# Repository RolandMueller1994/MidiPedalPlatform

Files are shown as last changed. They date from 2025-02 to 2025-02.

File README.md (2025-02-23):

# MidiPedalPlatform

## Introduction

This project contains a template PCB for guitar effect pedals with MIDI remote functionality. MIDI is implemented using a STM32 F030C8T6 microcontroller.
The PCB is setup to contain four 16mm potentiometers, a SPST on-off-on switch and PCB mounted jack sockets for audio connection. Further connections are the MIDI input and output, an internal switch and an external switch which are all accesible through JST connectors. A programming and debugging connector for the STLINK-V3MINIE is implemented on the PCB.

Following images show a complete pedal build based on this template.

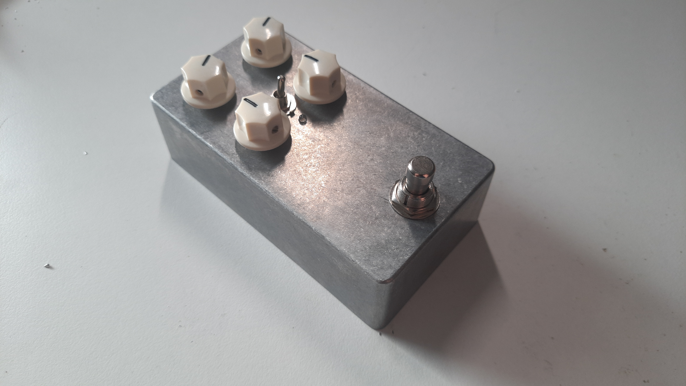
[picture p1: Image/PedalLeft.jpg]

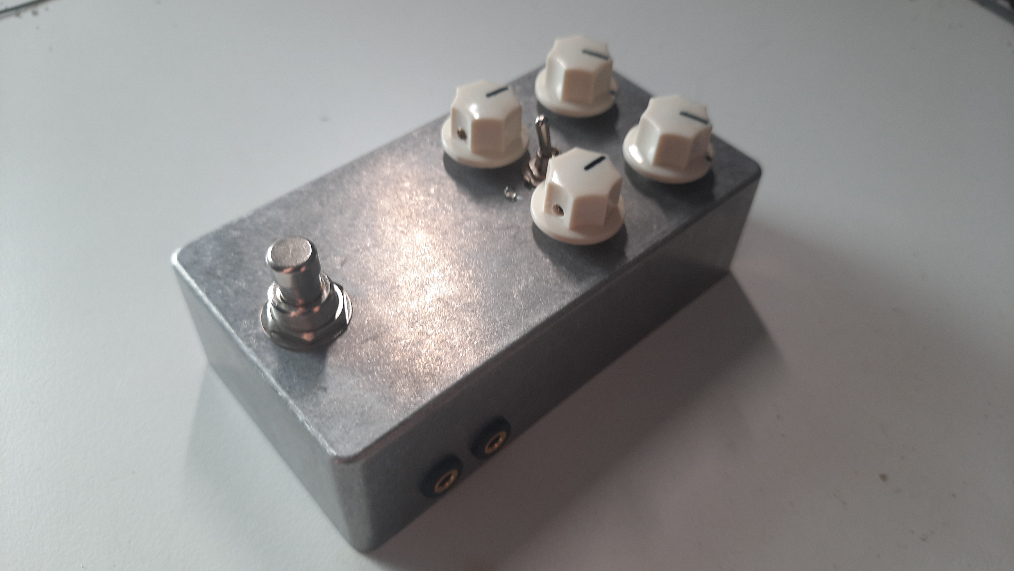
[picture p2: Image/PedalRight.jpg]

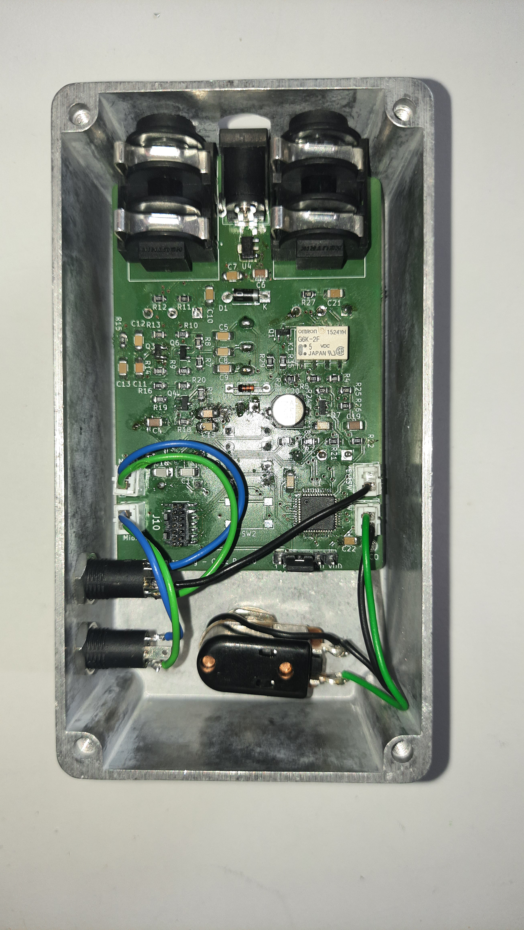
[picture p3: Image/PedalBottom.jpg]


## PCB

The PCB was developed using KiCad and a two layer setup. The KiCad project can be found in [PCB/MidiPedalPlatform](PCB/MidiPedalPlatform) whilst PCB and schematic exports are located in [PCB/Export](PCB/Export).

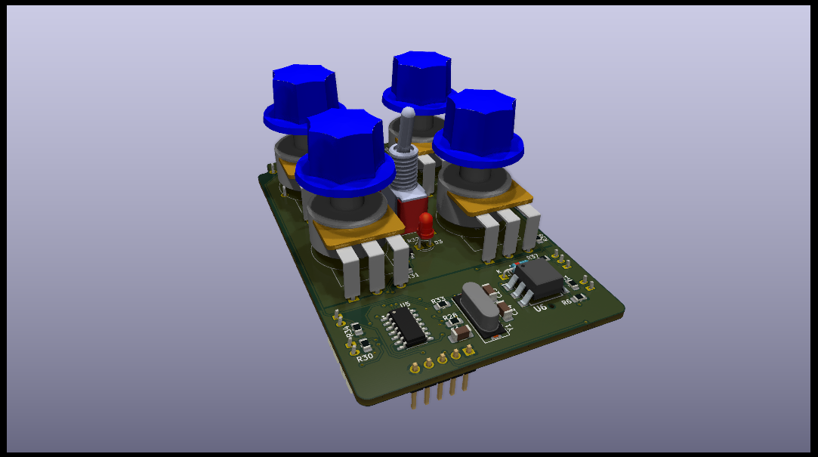
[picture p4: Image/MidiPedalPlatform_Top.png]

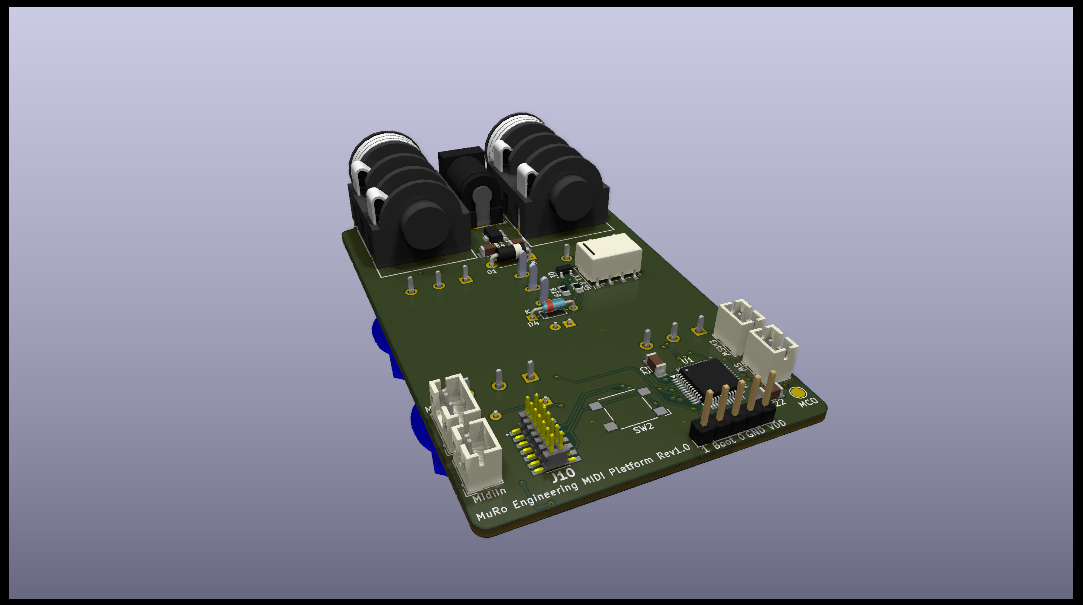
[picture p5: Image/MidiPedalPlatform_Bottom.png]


## Firmware

The MCU firmware is located in the [Firmware](Firmware) directory. It is implemented as STM32CubeIDE project.

The firmware handles switches and MIDI messages. By default, two switches are available: SW and ExtSW. SW is meant to be used as the default internal footswitch and must be a momentary switch. ExtSW can be used to connect an external remote switch and is by default configured to be a latching switch. This can be changed by changing:
```C
bool swLatches[NO_SWITCHES] = { false, true, true }
```
to
```C
bool swLatches[NO_SWITCHES] = { false, false, true }
```
The pedal can be switched on and off via MIDI CC commands. The channel and controller number are stored in the flash memory. Thus, a MIDI learn state and a reset state have been implemented.
To reset both parameters to their default value (channel=0, controller=20), hold the footswitch pressed (SW) while powering on or reseting the MCU till the LED starts blinking. Release the switch afterwards and the LED stops blinking. Default values will then have been written to flash.

MIDI learn is used to set any other channel and controller. This mode can be accessed by holding the footswitch pressed whilst the input jack is not connected. The LED starts blinking once MIDI learn state has been reached. In this mode, the firmware waits for a MIDI CC message and once the first one has been received, it will store the channel and controller of this message in the flash memory. MIDI learn can be aborted by pressing the footswitch again. In either case, MIDI CC received or MIDI learn aborted, the LED stops blinking.
The pedal can be switched on by sending a value greater than 63 to the configured MIDI contoller. Anything lower or equal than 63 will switch off the pedal.

The footswitch can be used in two different ways. 

- Normal activation: Toggles between on and off state
- Keeping the switch pressed whilst the pedal was off: The pedal will turn on as long you keep the switch pressed. Once release, the pedal will turn off.

## Enclosure

The PCB was design to fit into a 1590N1 enclosure. A FreeCAD project including enclosure, PCB, jacks and the switch can be found at [Enclosure/Enclosure.FCStd](Enclosure/Enclosure.FCStd). Renderings of the enclosure can be found below.
Drill templates can be found in [Enclosure/DrillTemplates](Enclosure/DrillTemplates).

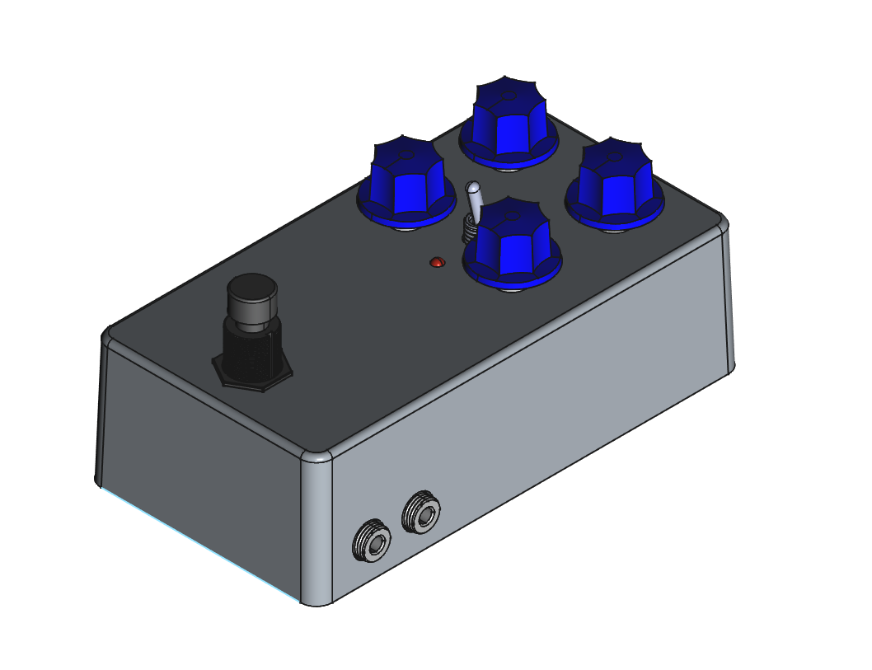
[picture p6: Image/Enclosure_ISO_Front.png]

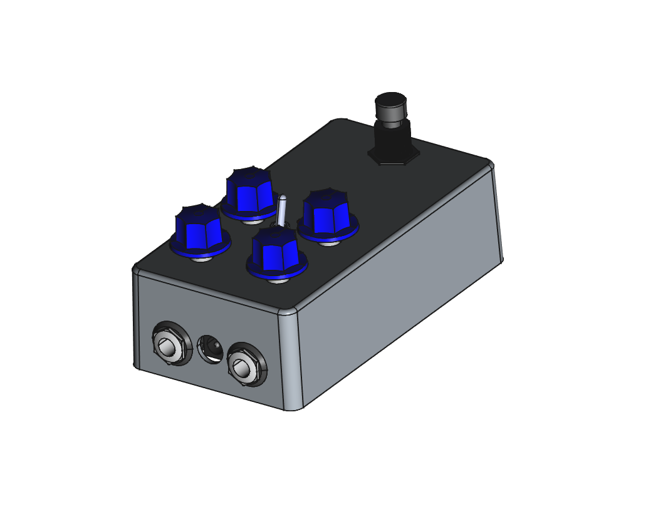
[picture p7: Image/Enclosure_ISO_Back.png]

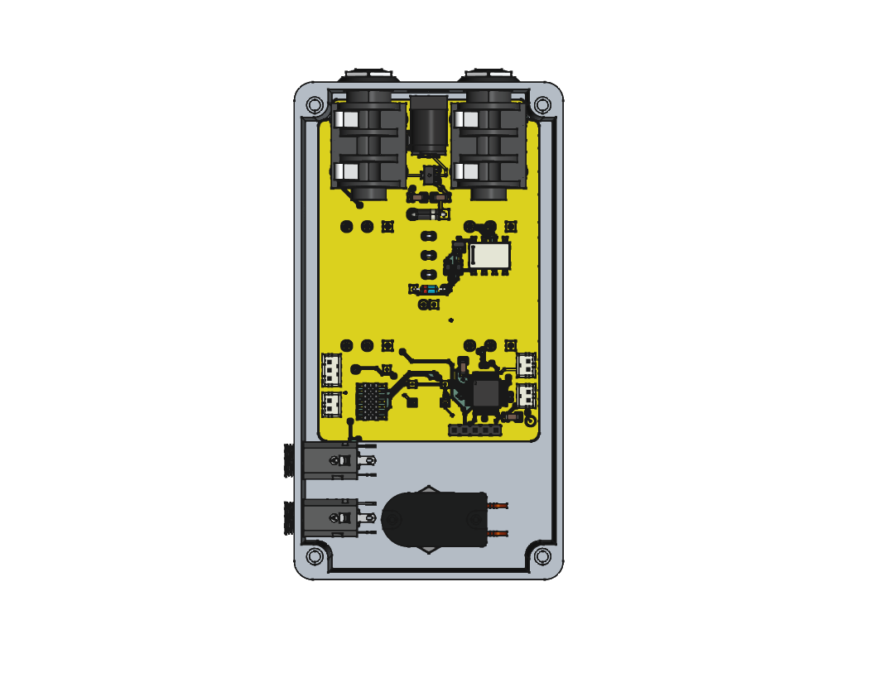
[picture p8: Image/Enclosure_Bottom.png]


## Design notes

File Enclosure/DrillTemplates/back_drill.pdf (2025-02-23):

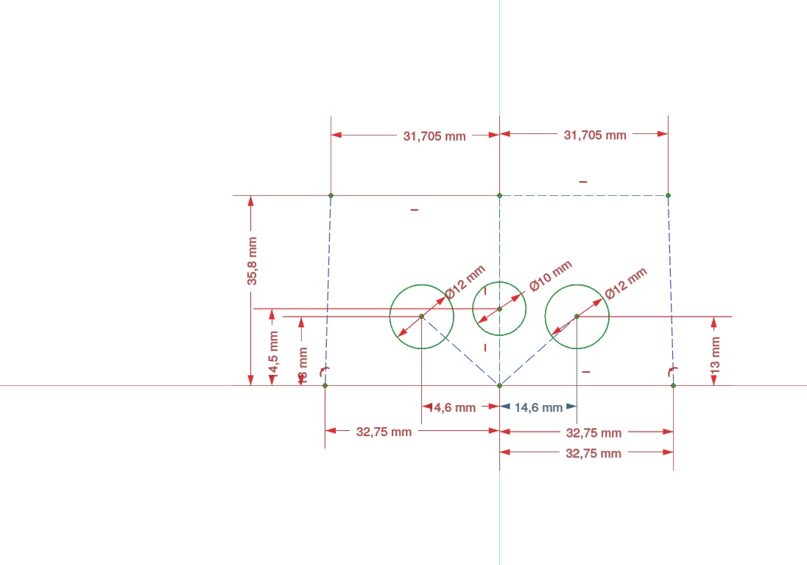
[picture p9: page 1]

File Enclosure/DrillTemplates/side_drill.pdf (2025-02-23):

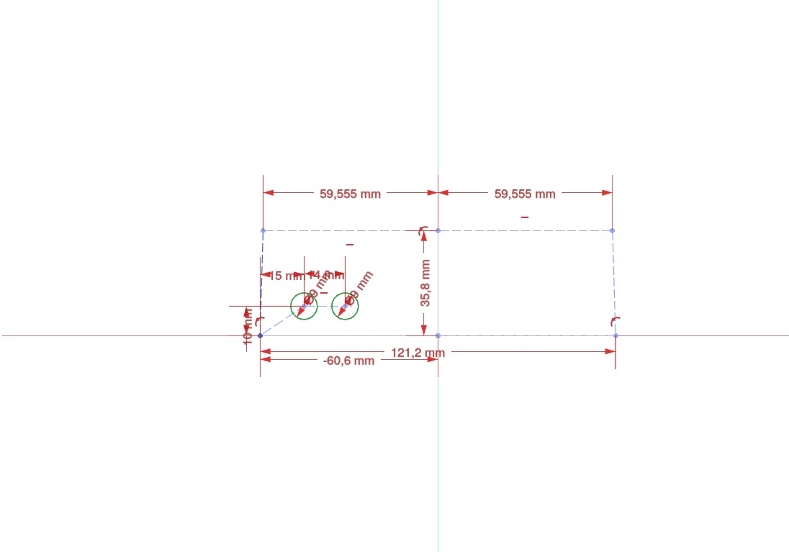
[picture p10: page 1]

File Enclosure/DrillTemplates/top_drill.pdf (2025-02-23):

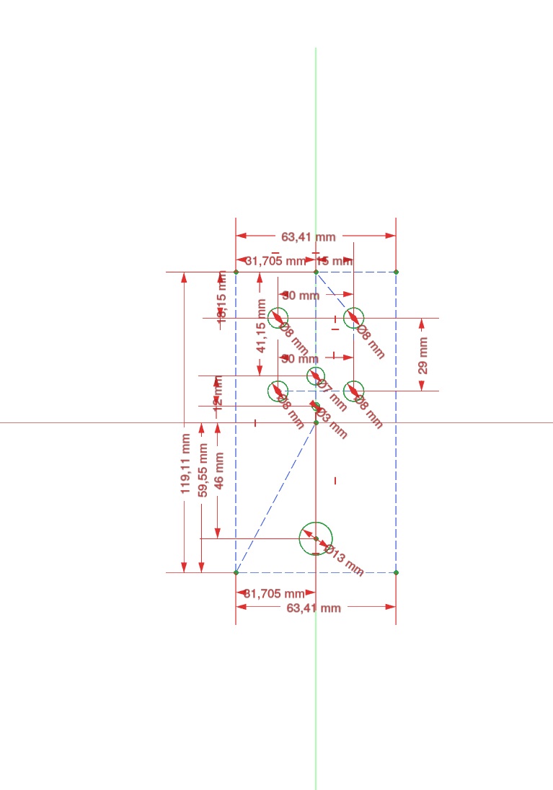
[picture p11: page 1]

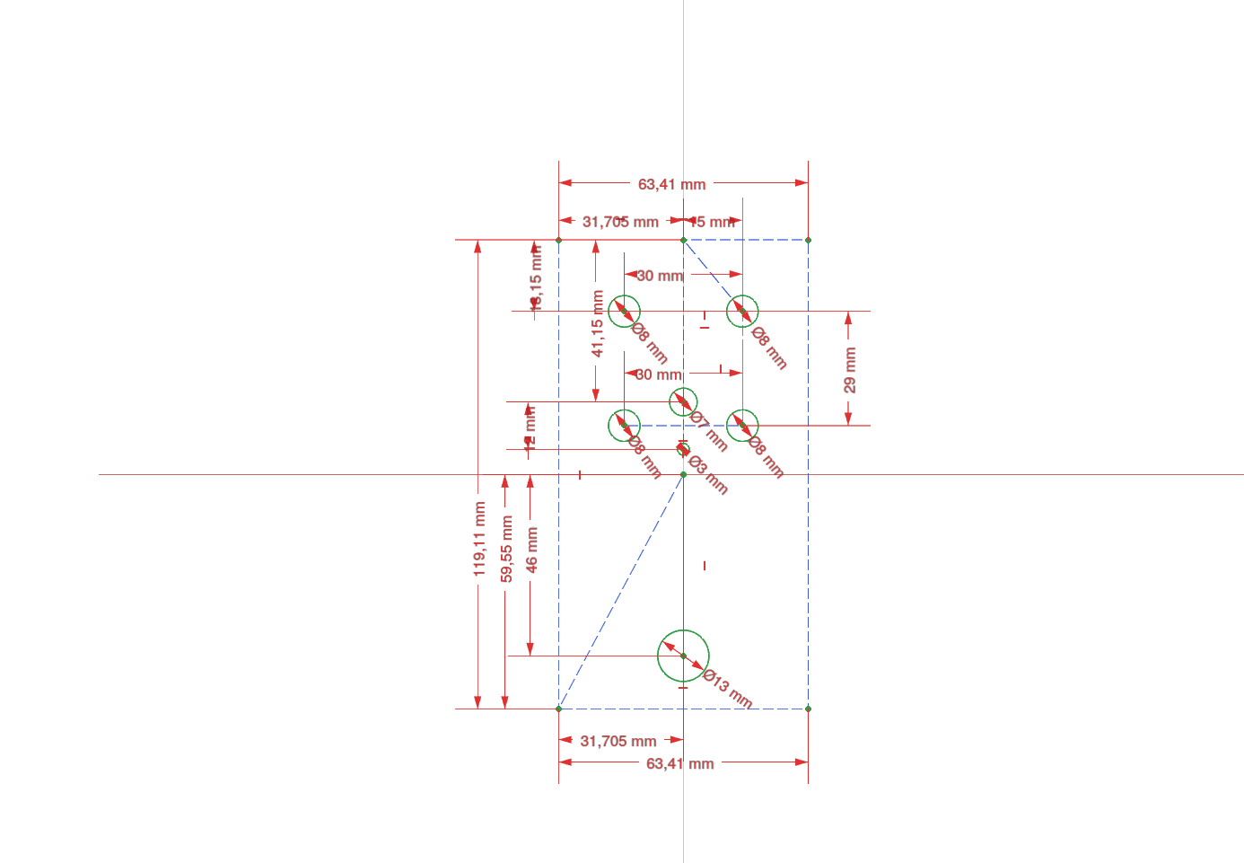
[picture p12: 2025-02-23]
Enclosure/DrillTemplates/top_drill.png

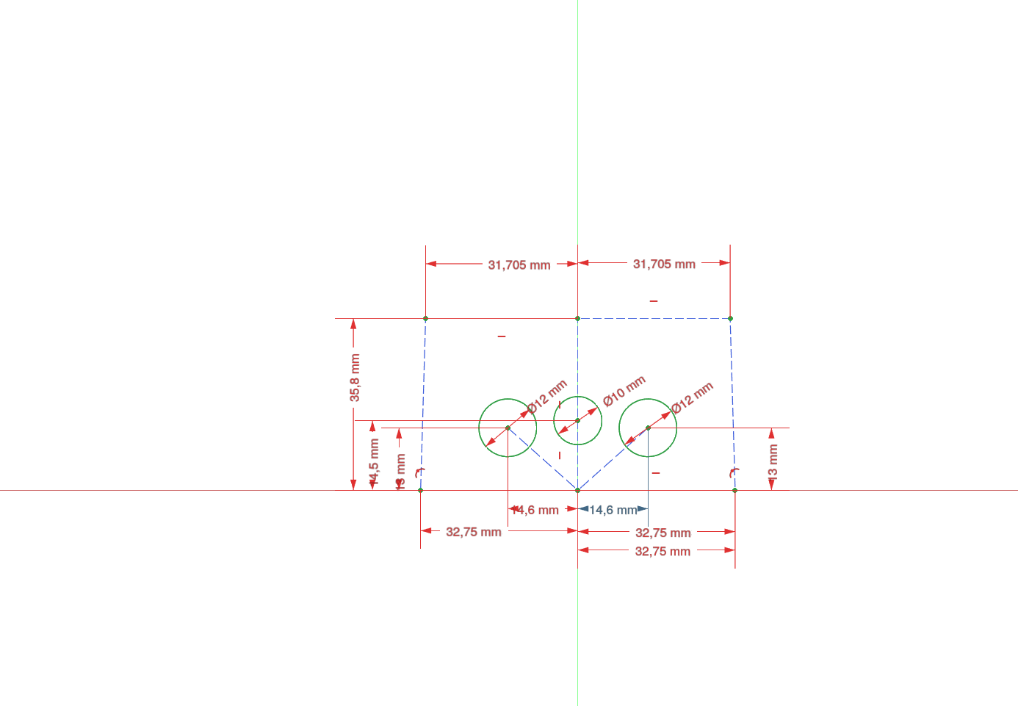
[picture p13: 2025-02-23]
Enclosure/DrillTemplates/back_drill.png

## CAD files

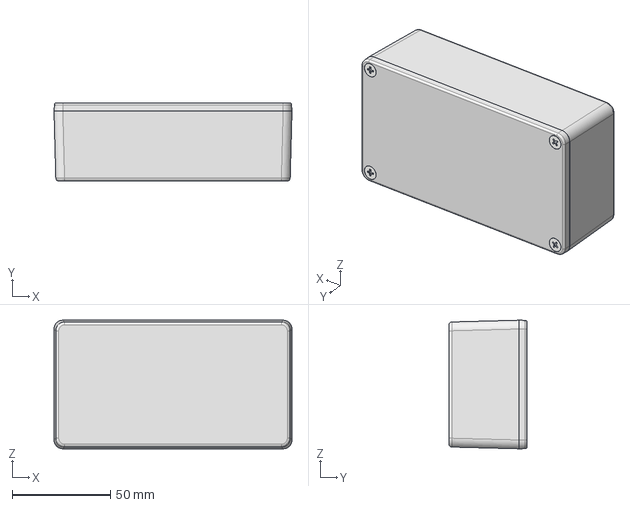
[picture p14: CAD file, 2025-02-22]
Enclosure/1590N1.stp
121.2 x 39.8 x 65.5 mm

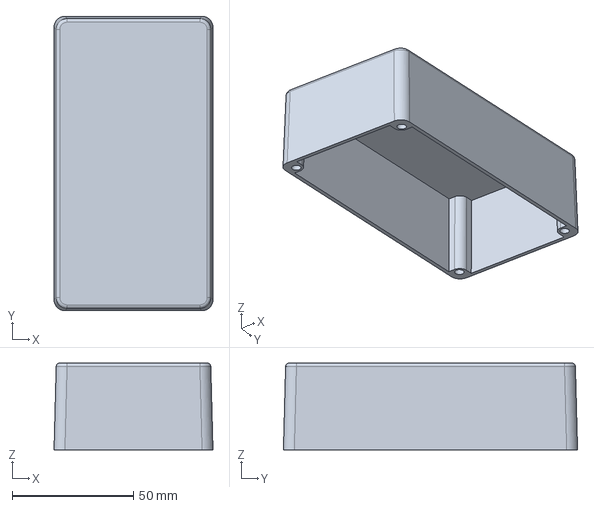
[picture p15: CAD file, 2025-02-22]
Enclosure/Enclosure.FCStd
65.5 x 121.2 x 35.8 mm

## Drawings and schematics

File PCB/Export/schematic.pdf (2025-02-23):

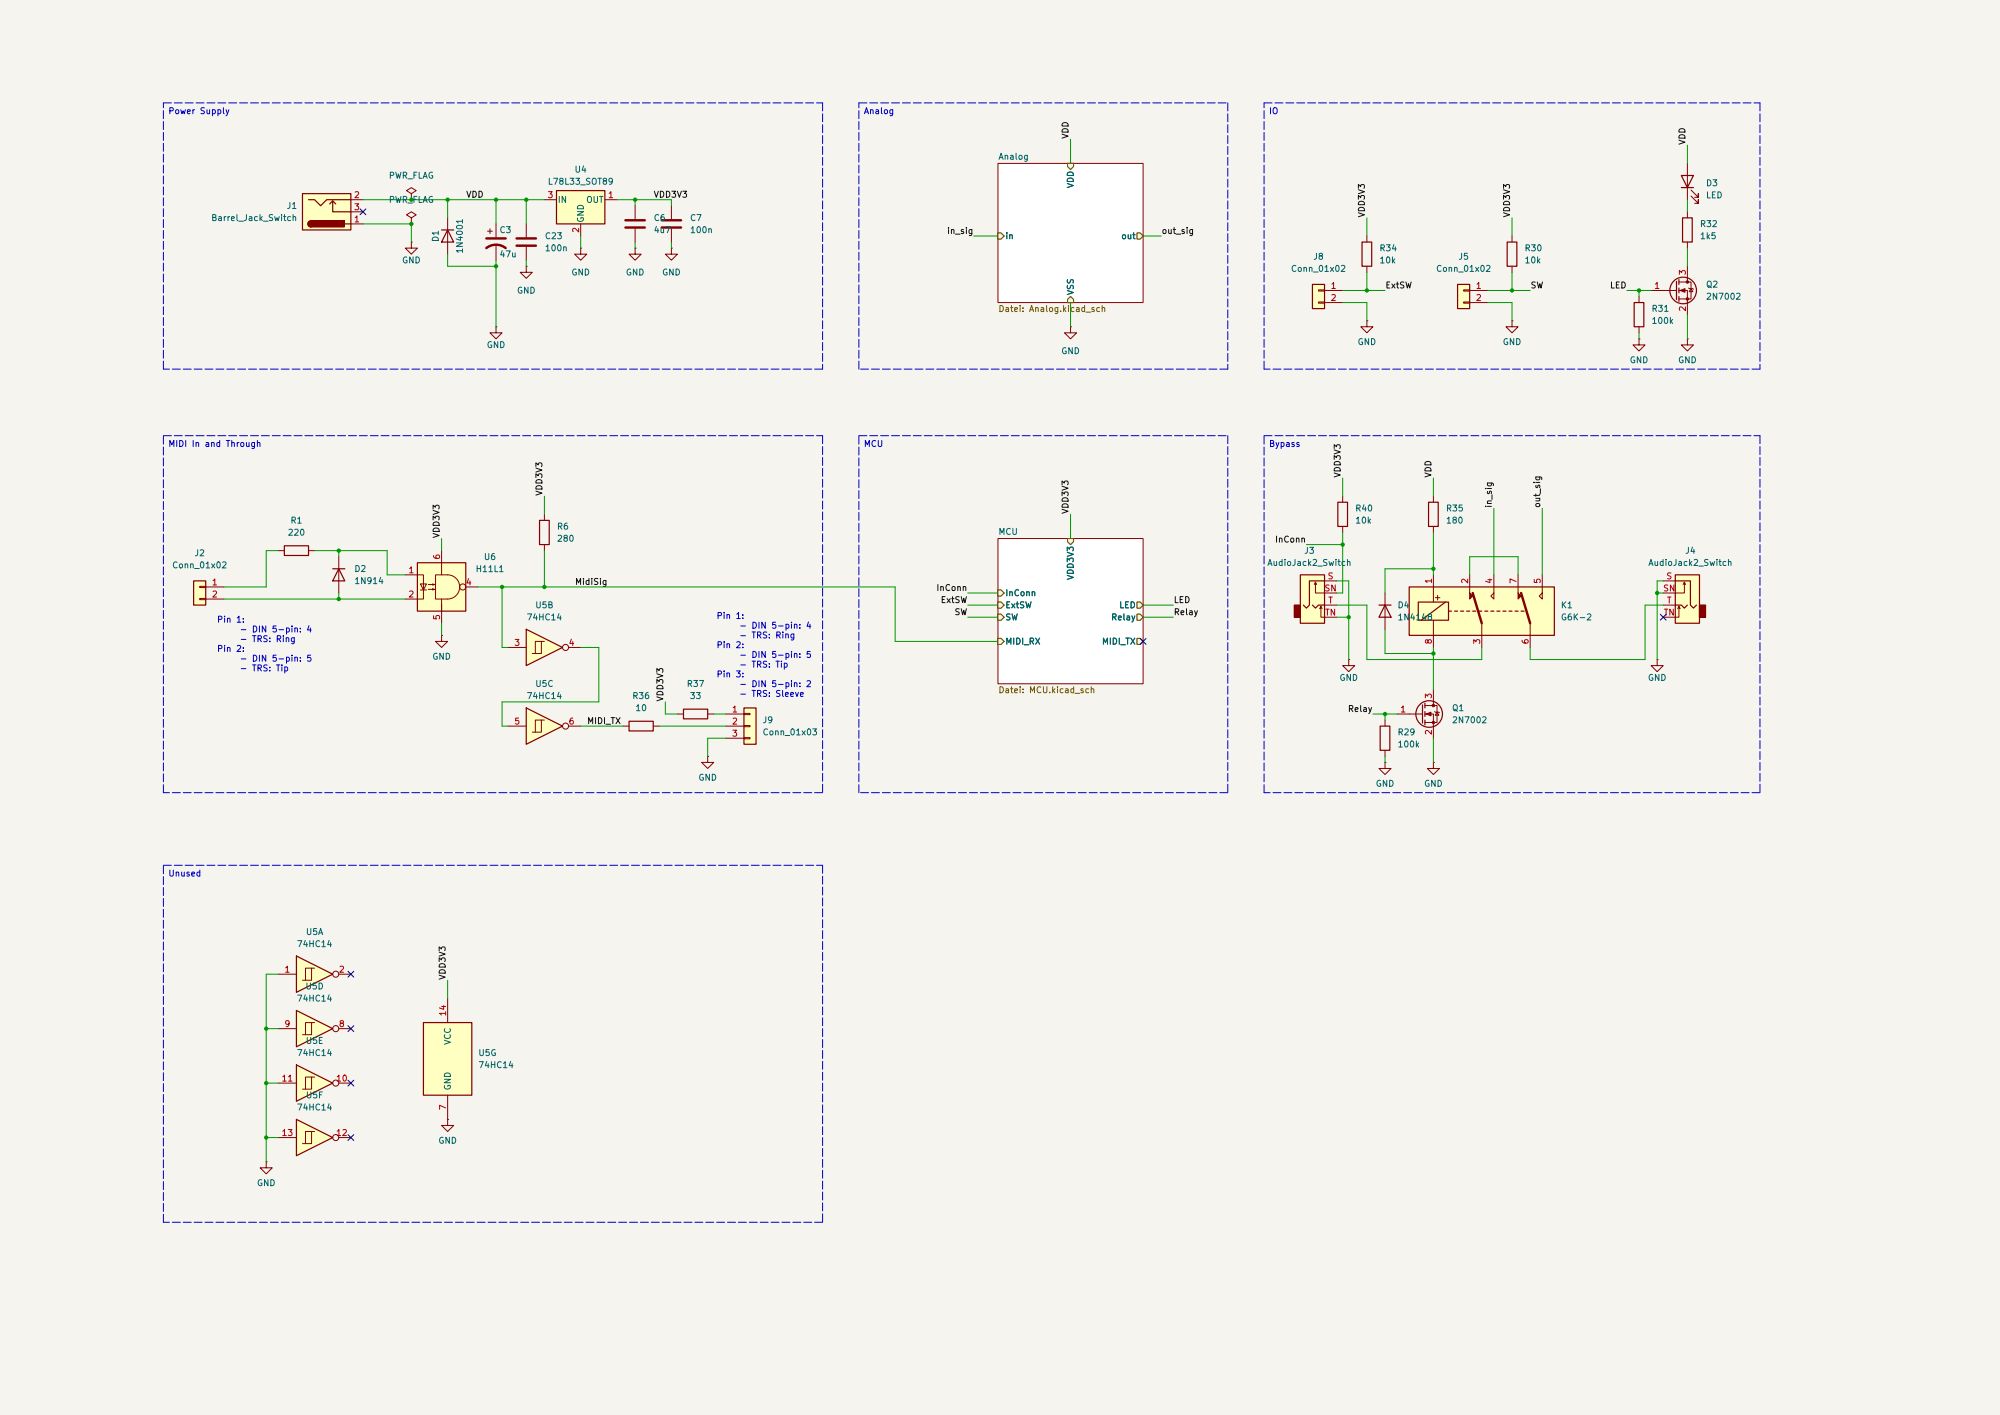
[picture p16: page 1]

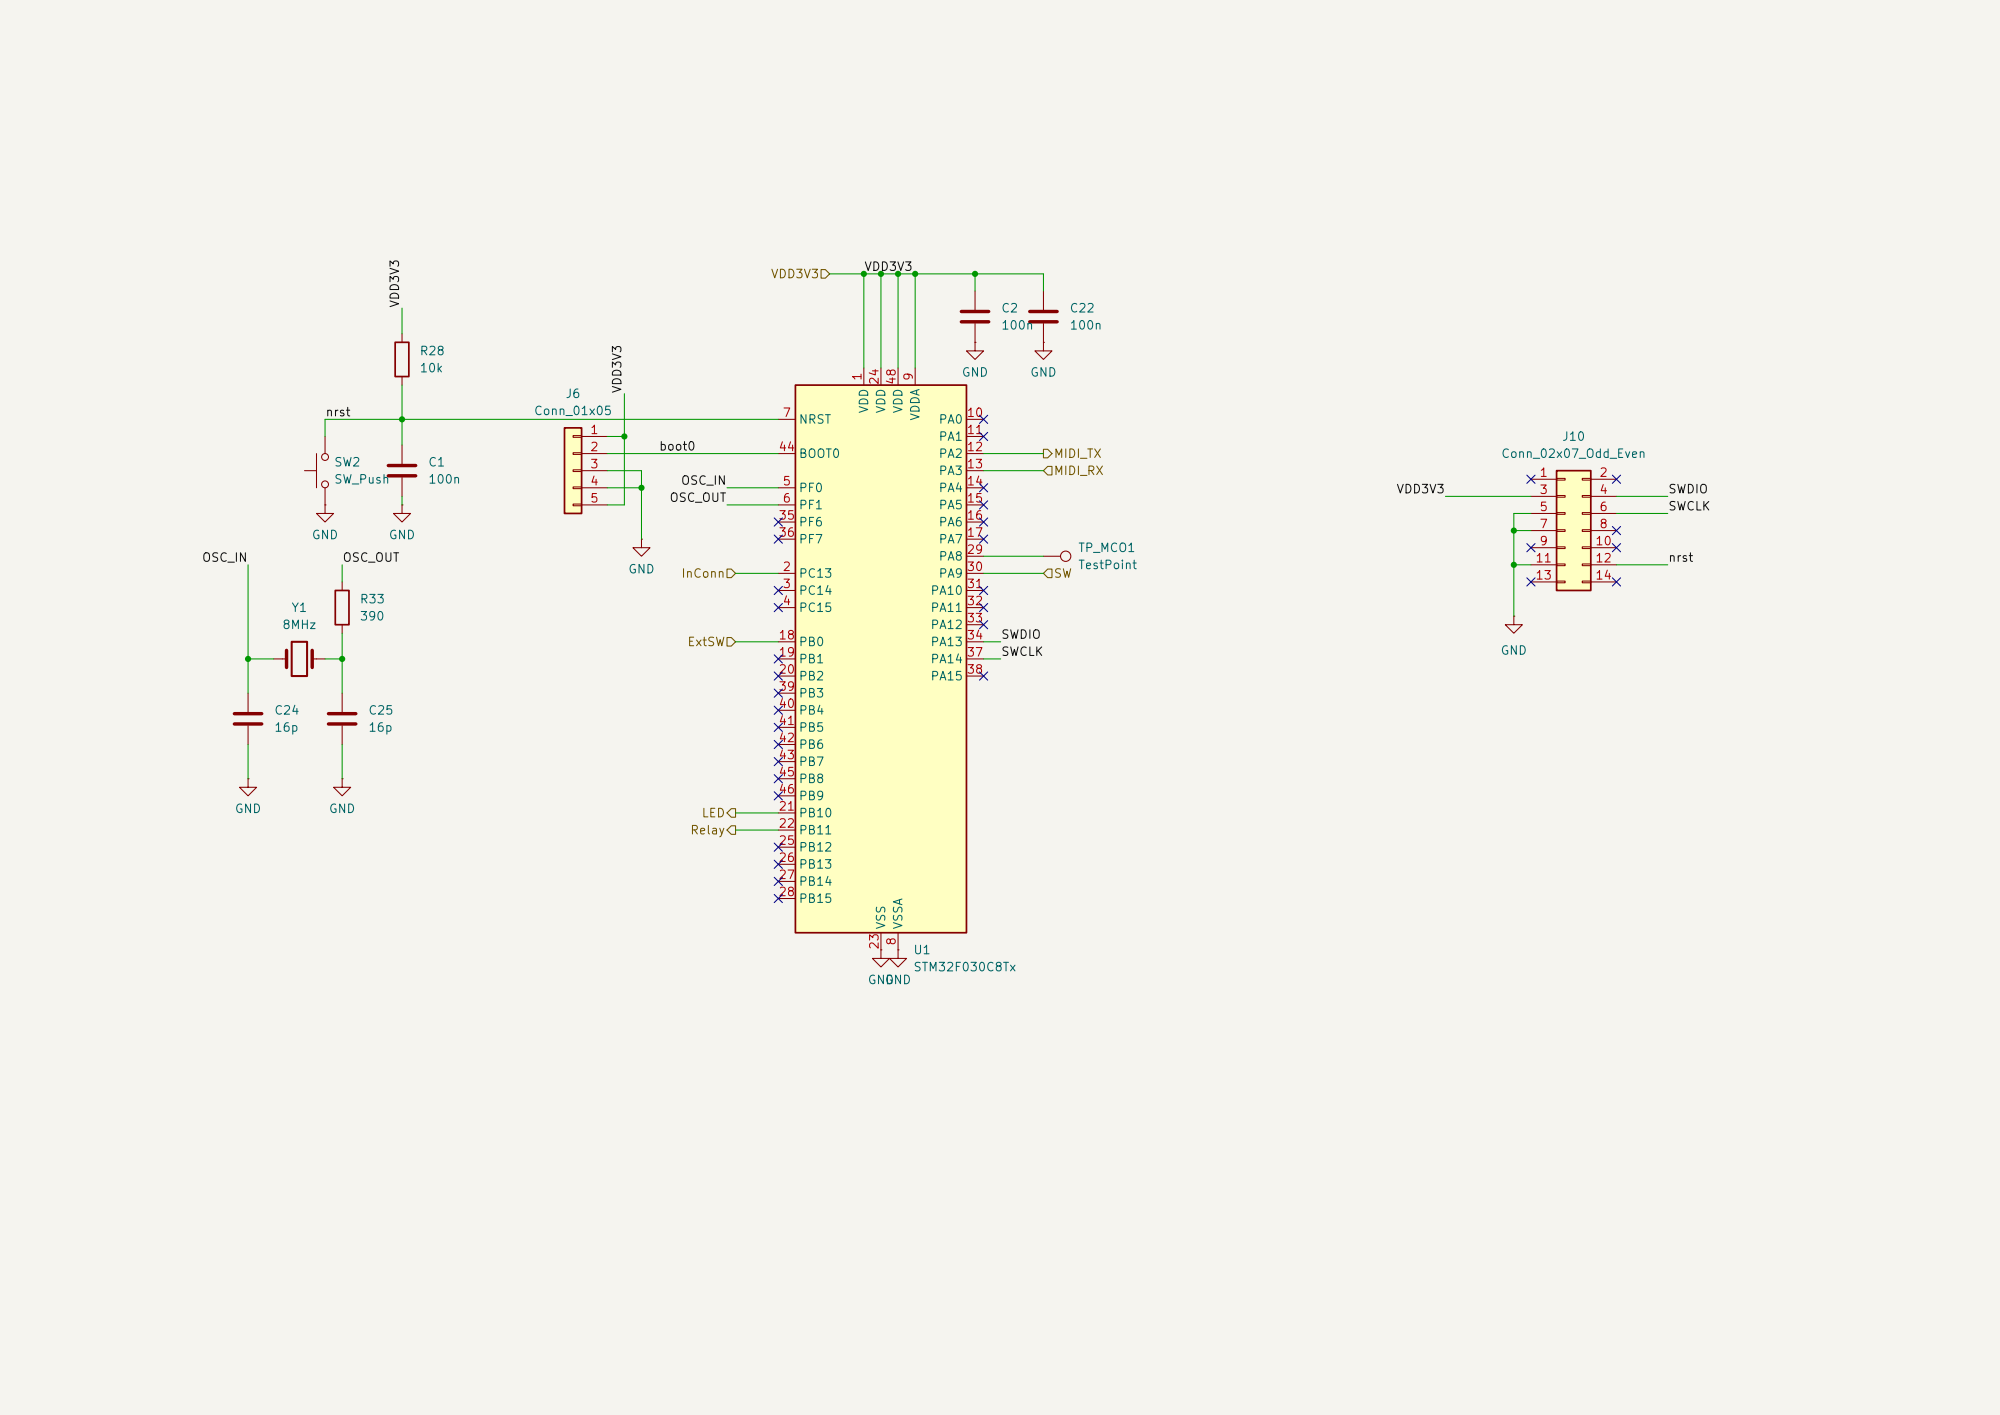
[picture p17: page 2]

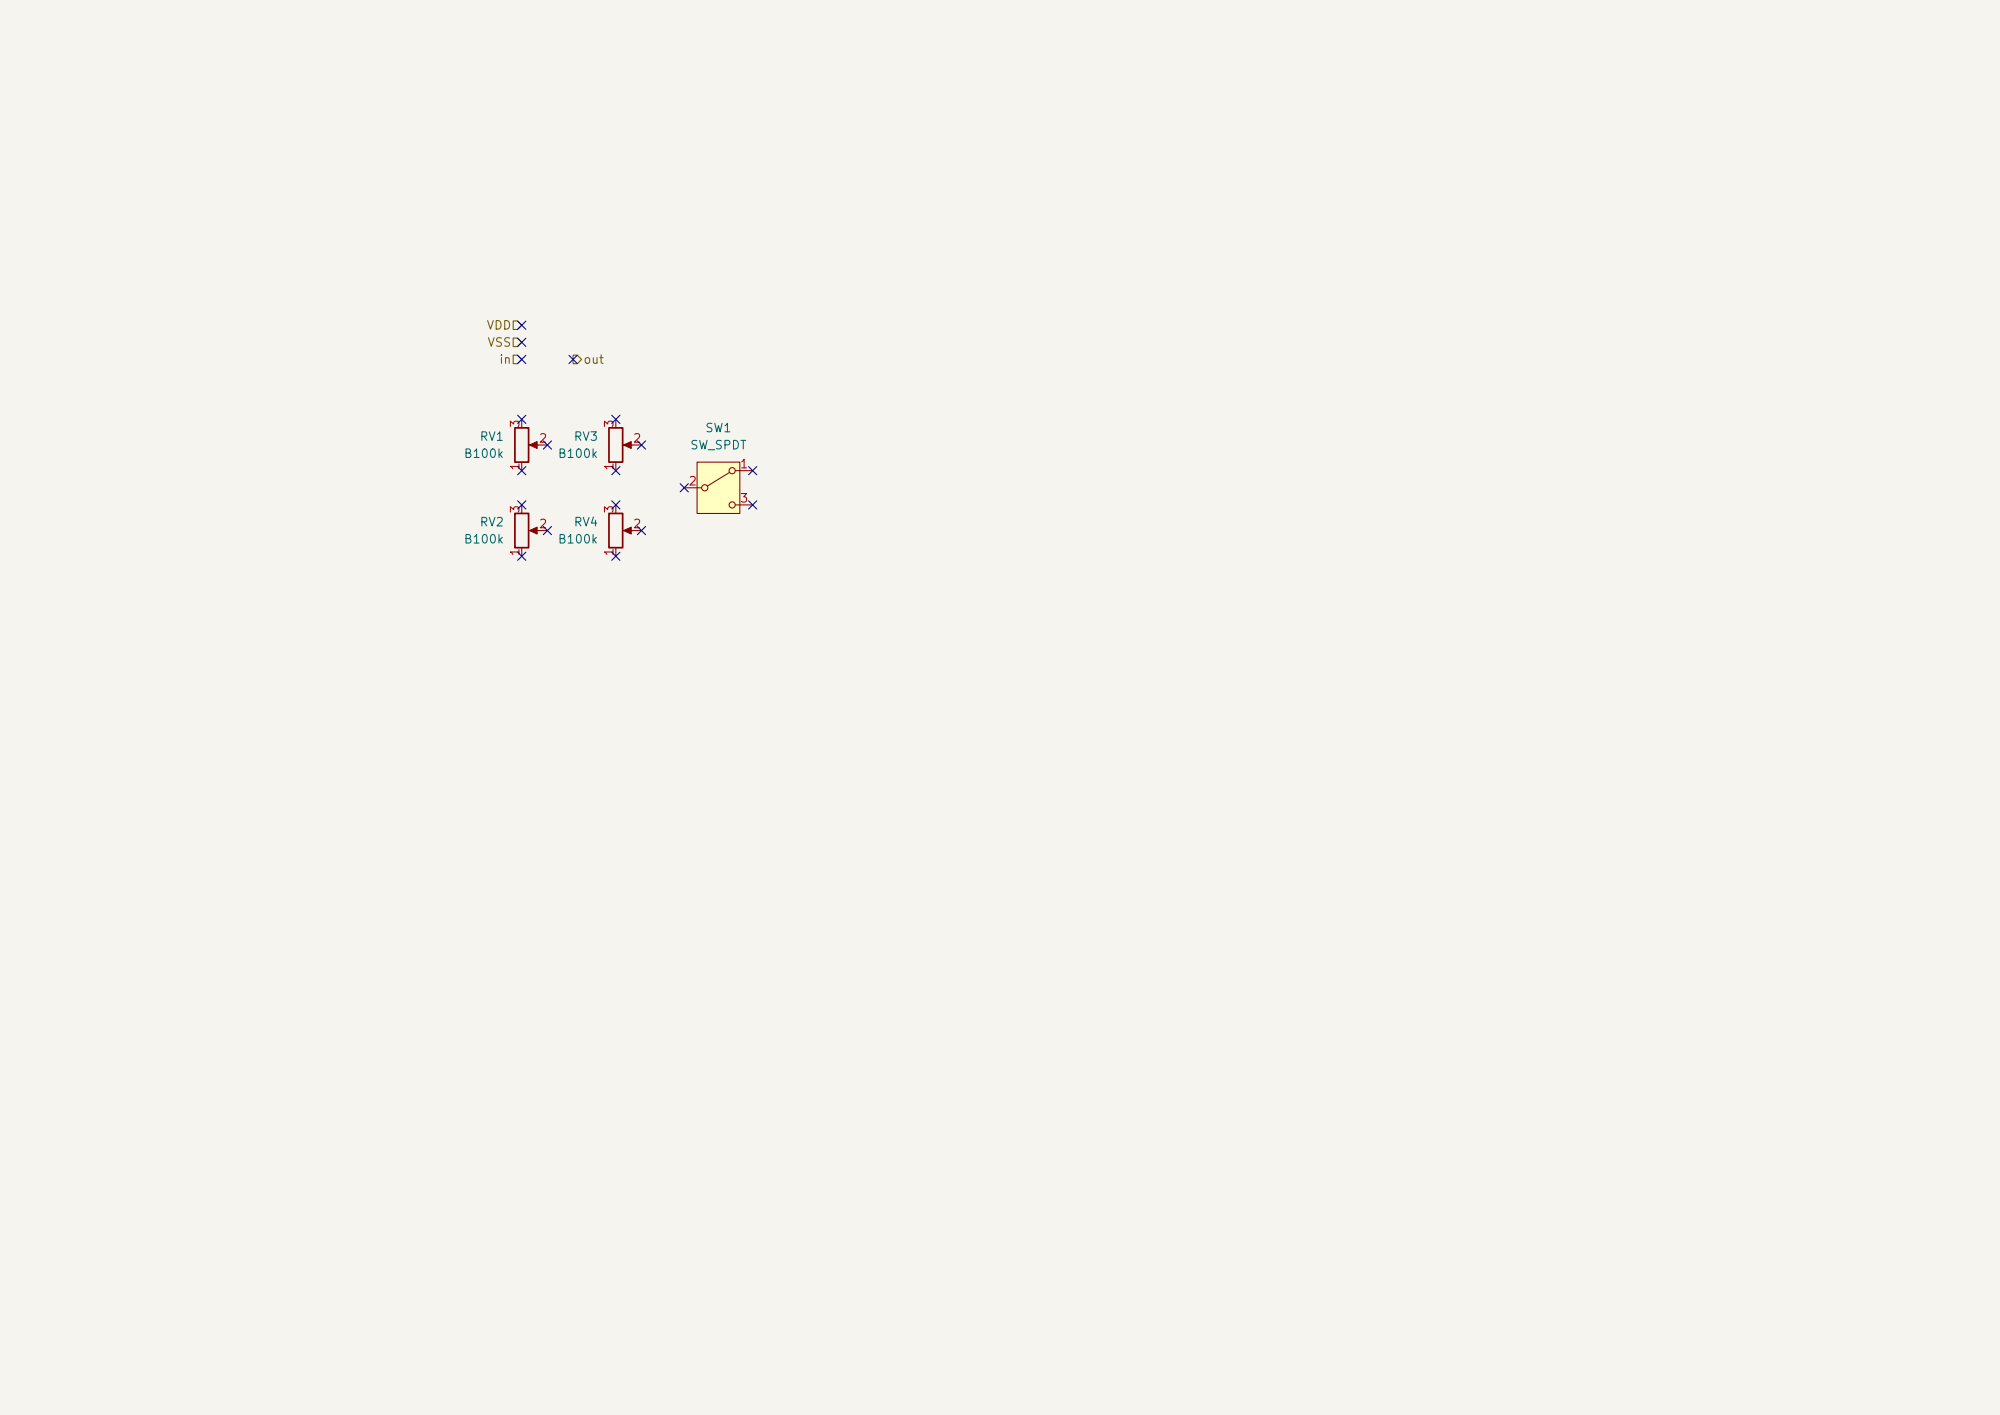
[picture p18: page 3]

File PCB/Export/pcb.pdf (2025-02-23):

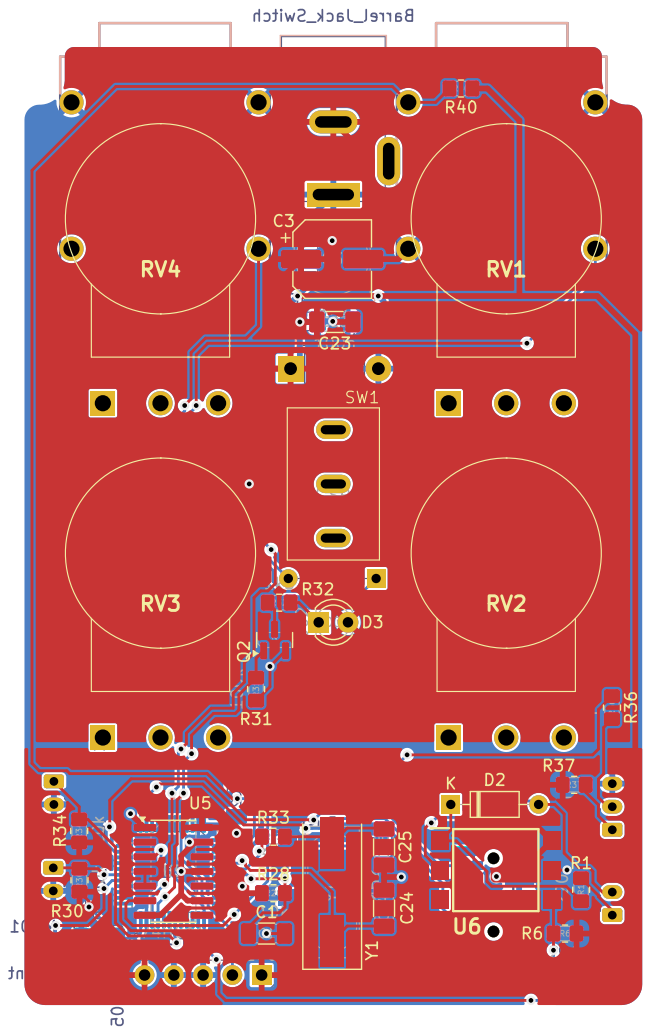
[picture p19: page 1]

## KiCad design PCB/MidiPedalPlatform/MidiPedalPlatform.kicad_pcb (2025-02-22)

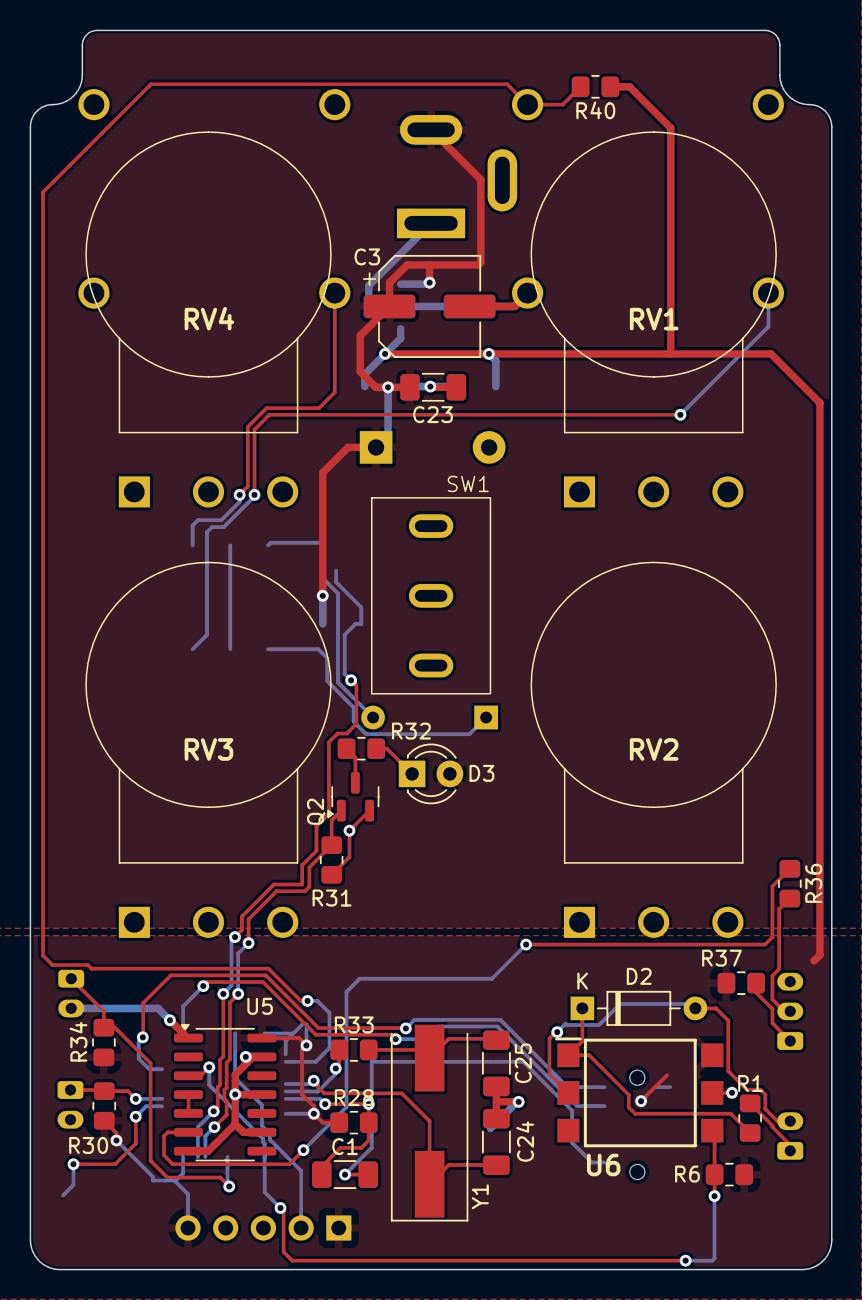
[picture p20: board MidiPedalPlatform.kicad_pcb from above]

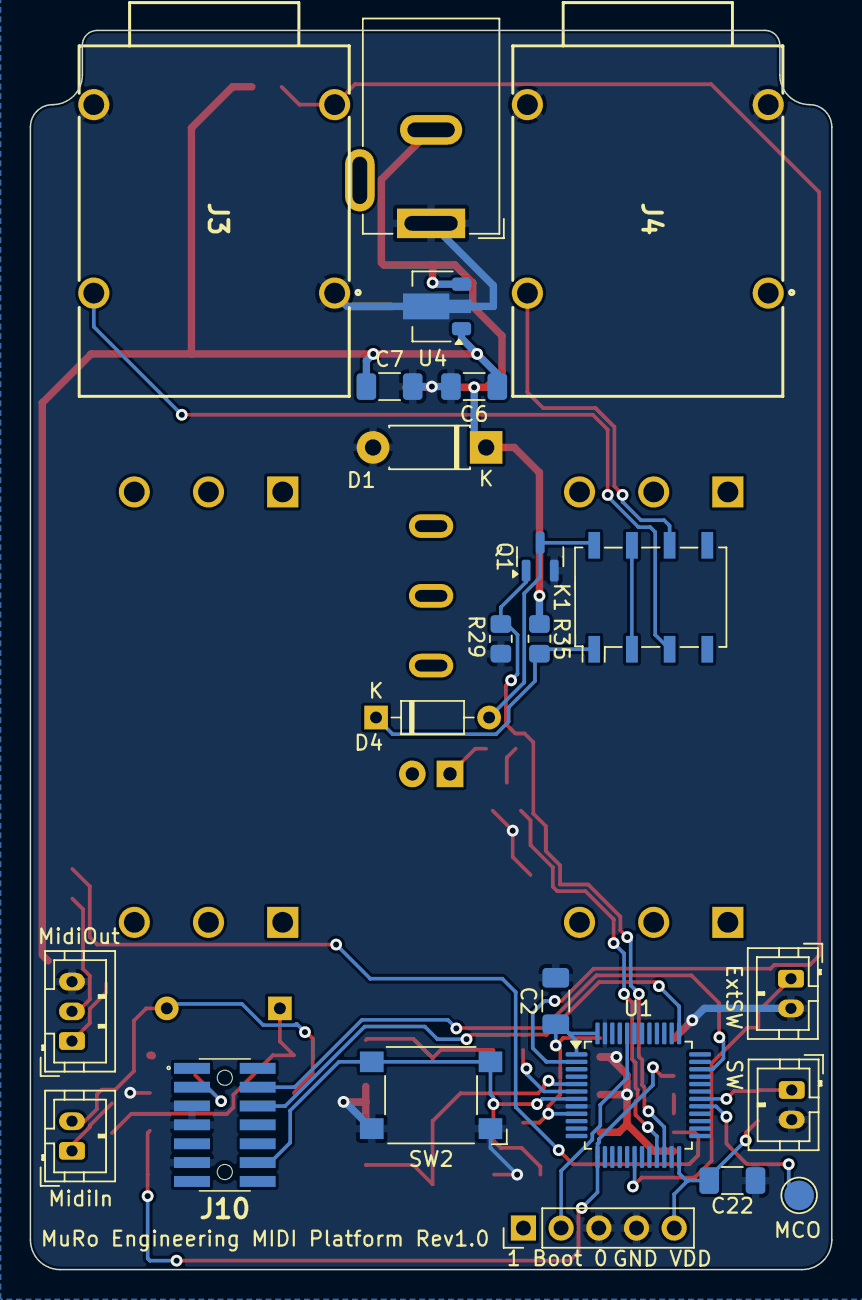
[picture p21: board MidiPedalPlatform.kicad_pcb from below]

Board: 2 copper layers, 54.0 x 83.5 mm, 50 parts (23 on the bottom side), 31 nets.

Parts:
C1, C2, C7, C22, C23: 100n; C_1206_3216Metric_Pad1.33x1.80mm_HandSolder
C3: 47u; CP_Elec_6.3x5.8
C6: 4u7; C_1206_3216Metric_Pad1.33x1.80mm_HandSolder
C24, C25: 16p; C_1206_3216Metric_Pad1.33x1.80mm_HandSolder
D1: 1N4001; D_DO-41_SOD81_P7.62mm_Horizontal
D2: 1N914; D_DO-35_SOD27_P7.62mm_Horizontal
D3: LED; LED_D3.0mm
D4: 1N4148; D_DO-35_SOD27_P7.62mm_Horizontal
J1: Barrel_Jack_Switch; BarrelJack_GCT_DCJ200-10-A_Horizontal
J2, J5, J8: Conn_01x02; JST_PH_B2B-PH-K_1x02_P2.00mm_Vertical
J3, J4: AudioJack2_Switch; NMJ4HCD2
J6: Conn_01x05; PinHeader_1x05_P2.54mm_Vertical
J9: Conn_01x03; JST_PH_B3B-PH-K_1x03_P2.00mm_Vertical
J10: Conn_02x07_Odd_Even; FTSH-107-XX-YYY-DV-K-A
K1: G6K-2; Relay_DPDT_Omron_G6K-2F
Q1, Q2: 2N7002; SOT-23
R1: 220; R_0805_2012Metric_Pad1.20x1.40mm_HandSolder
R6: 280; R_0805_2012Metric_Pad1.20x1.40mm_HandSolder
R28, R30, R34, R40: 10k; R_0805_2012Metric_Pad1.20x1.40mm_HandSolder
R29, R31: 100k; R_0805_2012Metric_Pad1.20x1.40mm_HandSolder
R32: 1k5; R_0805_2012Metric_Pad1.20x1.40mm_HandSolder
R33: 390; R_0805_2012Metric_Pad1.20x1.40mm_HandSolder
R35: 180; R_0805_2012Metric_Pad1.20x1.40mm_HandSolder
R36: 10; R_0805_2012Metric_Pad1.20x1.40mm_HandSolder
R37: 33; R_0805_2012Metric_Pad1.20x1.40mm_HandSolder
RV1, RV2, RV3, RV4: B100k; RV16AF_Mono
SW1: SW_SPDT; Switch_SPDT
SW2: SW_Push; SW_SPST_Omron_B3FS-100xP
TP_MCO1: TestPoint; TestPoint_Pad_D2.0mm
U1: STM32F030C8Tx; LQFP-48_7x7mm_P0.5mm
U4: L78L33_SOT89; SOT-89-3
U5: 74HC14; SO-14_3.9x8.65mm_P1.27mm
U6: H11L1; H11L1SM
Y1: 8MHz; Crystal_SMD_HC49-SD

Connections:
/ExtSW: J8.1, R34.2, U1.18 (PB0)
/InConn: J3.SN, R40.2, U1.2 (PC13)
/LED: Q2.1 (G), R31.1, U1.21 (PB10)
/MCU/OSC_IN: C24.1, U1.5 (PF0), Y1.1
/MCU/OSC_OUT: R33.1, U1.6 (PF1)
/MCU/SWCLK: J10.6, U1.37 (PA14)
/MCU/SWDIO: J10.4, U1.34 (PA13)
/MCU/boot0: J6.2, U1.44 (BOOT0)
/MCU/nrst: C1.1, J10.12, R28.2, SW2.2, U1.7 (NRST)
/MIDI_TX: R36.1, U5.6
/MidiSig: R6.1, U1.13 (PA3), U5.3, U6.4
/Relay: Q1.1 (G), R29.1, U1.22 (PB11)
/SW: J5.1, R30.2, U1.30 (PA9)
/VDD: C3.1, C23.1, D1.1 (K), D3.2 (A), J1.2, R35.1, U4.3 (IN)
/VDD3V3: C2.1, C6.1, C7.1, C22.1, J6.1, J6.5, J10.3, R6.2, R28.1, R30.1, R34.1, R37.1, R40.1, U1.1 (VDD), U1.9 (VDDA), U1.24 (VDD), U1.48 (VDD), U4.1 (OUT), U5.14 (VCC), U6.6
GND: C1.2, C2.2, C3.2, C6.2, C7.2, C22.2, C23.2, C24.2, C25.2, D1.2 (A), J1.1, J3.S, J3.TN, J4.S, J4.SN, J5.2, J6.3, J6.4, J8.2, J9.3, J10.5, J10.7, J10.11, Q1.2 (S), Q2.2 (S), R29.2, R31.2, SW2.1, U1.8 (VSSA), U1.23 (VSS), U1.47 (VSS), U4.2 (GND), U5.1, U5.7 (GND), U5.9, U5.11, U5.13, U6.5
unnamed: C25.1, R33.2, Y1.2
unnamed: D2.2 (A), J2.2, U6.2
unnamed: D2.1 (K), R1.2, U6.1
unnamed: D3.1 (K), R32.1
unnamed: D4.2 (A), K1.8, Q1.3 (D)
unnamed: D4.1 (K), K1.1, R35.2
unnamed: J2.1, R1.1
unnamed: J3.T, K1.3
unnamed: J4.T, K1.6
unnamed: J9.1, R37.2
unnamed: J9.2, R36.2
unnamed: K1.2, K1.7
unnamed: Q2.3 (D), R32.2
unnamed: TP_MCO1.1, U1.29 (PA8)
unnamed: U5.4, U5.5

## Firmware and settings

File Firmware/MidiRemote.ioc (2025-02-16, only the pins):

Mcu.UserName=STM32F030C8Tx
PA13.Signal=SYS_SWDIO
PA14.Signal=SYS_SWCLK
PA2.Signal=USART2_TX
PA3.Signal=USART2_RX
PA8.Signal=RCC_MCO
PA9.GPIO_Label=SW
PA9.Signal=GPIO_Input
PB0.GPIO_Label=ExtSW
PB0.Signal=GPIO_Input
PB10.GPIO_Label=LED
PB10.Signal=GPIO_Output
PB11.GPIO_Label=Relay
PB11.Signal=GPIO_Output
PC13.GPIO_Label=InConn
PC13.Signal=GPIO_Input
PF0-OSC_IN.Signal=RCC_OSC_IN
PF1-OSC_OUT.Signal=RCC_OSC_OUT

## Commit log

2025-02-16 Imported firmware with basic hardware configuration. This is a clean STM32 project for the target microcontroller including the IO configuration.
2025-02-16 First version of switch debouncing.
    In this version, momentary switches are properly debounced and their state is traced for falling edge (active low) operation.
    Dual edge debouncing and latching switch operation yet to be implemented.
2025-02-16 Added push and release edge detection and debouncing.
    With this change, lateched switches can be used to trigger the effectOn state by tracking the edges.
2025-02-16 Added long press functionality for momentary switches.
    This feature detects momentary switches been pressed for longer than a certain time (LONG_DELAY). This can be used to temporarily activate the effect as long as the switched is pressed. After release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
2025-02-16 Switched UART to UARTEx functions to use ReceiveToIdle functions.
    MIDI packages are either two or three bytes long. Thus, e.g. PC messages would not fill the whole RX buffer and therefore mess up the package sequence.
    ReceiveToIdle executes the callback once the length is reached or no further data is transfered (idle). Therefore, the interupts are called after each MIDI package no matter the length.
2025-02-16 Added MIDI learn functionality and reset.
    If the main switch is pressed at power on, default MIDI channel 1 and controller 20 are stored.
    If the main switch is pressed during operation and the input jack is not connected, MIDI learn is started. In this case, the device waits till it receives the first CC message. The channel and controller are stored afterwards.
    [main.c]
2025-02-18 Addition of periodic UART overrun check.
    UART gets into overrun condition once it receives data and the previous data has not been consumed by the application yet. In this case the ORE bit (bit 3) in the ISR register is set to 1 which disables all further interrupts. As this can happen at any time, we periodically check the ORE bit and re-issue the interrupt in case it is set to high.
    This can broken interrupts after midi learn and write to flash. During write to flash, the interrupts and therefore the data are not consumed which leads to broken interupts.
    [main.c]
2025-02-18 Changes: - Default midi channel set to 0 - Wait at reset till switch is released. Before we would get into midi learn if the switch is not release quickly enough. - Reset loop count in main once midi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
    [main.c]
2025-02-22 Added FreeCAD project with import Hammond 1590N1 enclosure
    [Enclosure.FCStd]
2025-02-22 Added PCB and the required components.
    Layout and schematic are matching. There are 15 warnings DRC warnings expected from silkscreen being clipped by other components or PCB edge.
    [ABC.kicad_sch, Analog.kicad_sch, Enclosure.FCStd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]
2025-02-22 Removed bom
    [bom.csv, bom.ods]
2025-02-22 Removed backup files
    [ABC.kicad_sch]
2025-02-22 Enclosure version with cutouts for parts. Midi input and output jacks still missing.
    [1590N1.stp]
2025-02-23 Added images and exports. Enclosure now contains 3.5mm jacks for MIDI in and out
